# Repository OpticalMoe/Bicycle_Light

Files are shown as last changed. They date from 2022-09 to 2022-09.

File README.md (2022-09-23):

# Bicycle_Light
自行车灯系列

**开源协议：CC-BY-NC-SA 3.0，知识共享许可协议-署名-非商业使用-相同方式共享。**

---

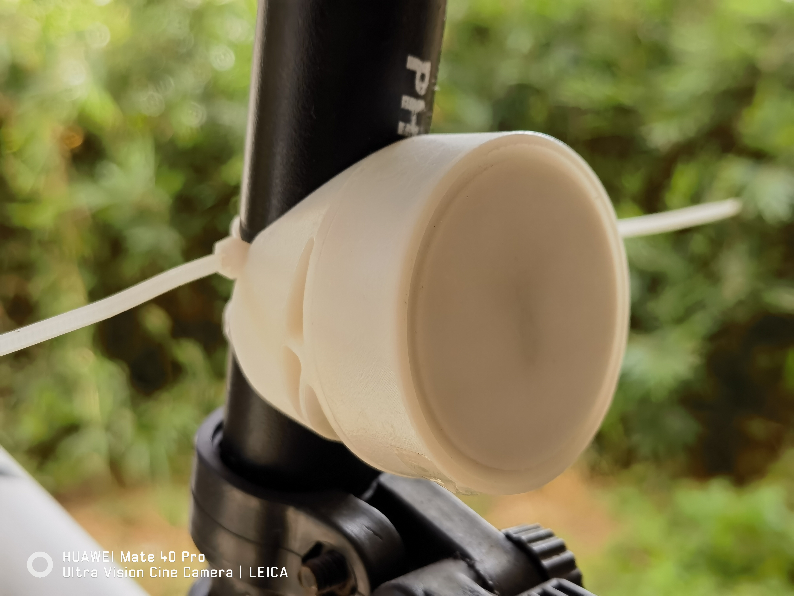
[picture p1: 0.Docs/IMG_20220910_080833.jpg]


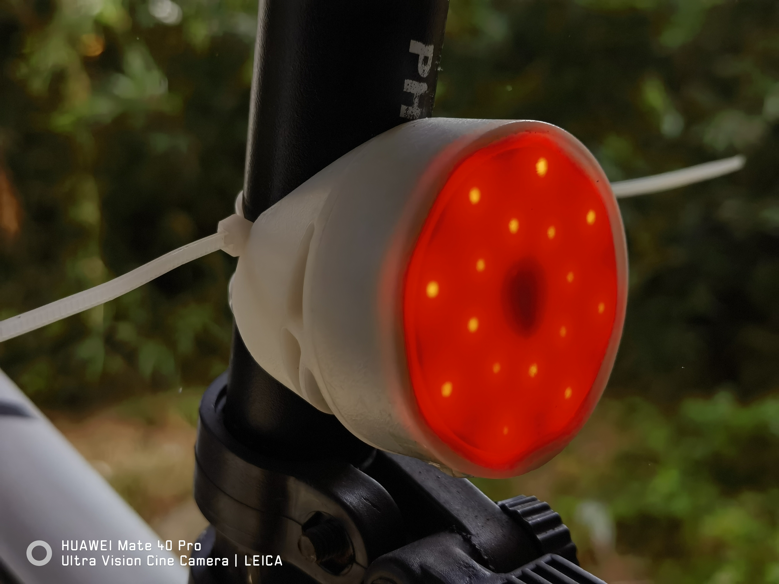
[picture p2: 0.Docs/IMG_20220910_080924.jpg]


> 目前仅有尾灯

# 尾灯

> 已知问题： (寒假改)
> 
>   1. 待机电流大，800mAh电池也就待机三天左右。下一版将会给非mcu器件加电子开关，待机时断开电源；
> 
>   2. 环境光API写了，逻辑部分没写；
> 
>   3. STC是QFN封装，对烙铁用户不友好；
>
>   4. 霍尔传感器“防盗”没测试；
> 
>   5. 刹车功能较难触发（急刹和撞墙才能识别到），且过沟沟坎坎会误触发。下一版取消（或更换传感器）。
> 
>   6. STC手册说是可以使用模拟USB下载程序，但是我电脑无法枚举设备，被迫转了串口下载。现支持不断电下载。 ：(

## 硬件
https://oshwhub.com/opticalmoe/bicycle_light

1. STC8G1K08-QFN20；

2. 16通道LED恒流驱动 TM5020A；

3. TC4056A 设定400mA充电电流；

4. 800mAh聚合物电池，30*34mm；

## 固件
1. 晃动/按键开机，无动作20s/按键关机；

2. 正面左按键开关机，右按键显示电量。一颗灯代表10%。

## 结构
Fusion360

---

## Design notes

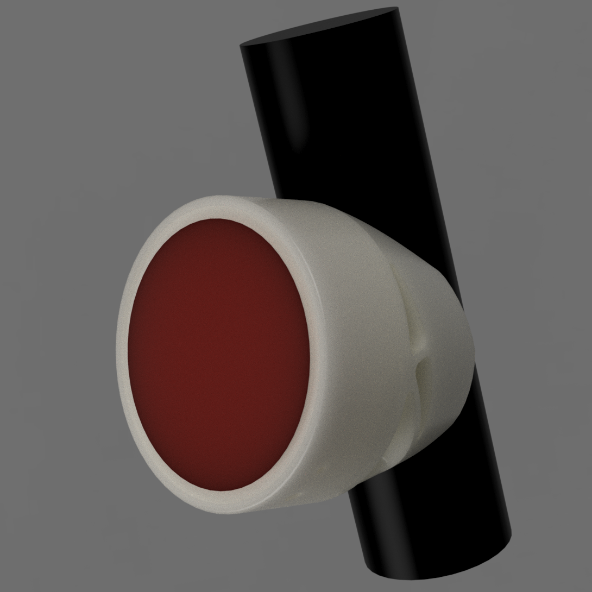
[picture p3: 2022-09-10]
5.结构/外壳 _F2.png

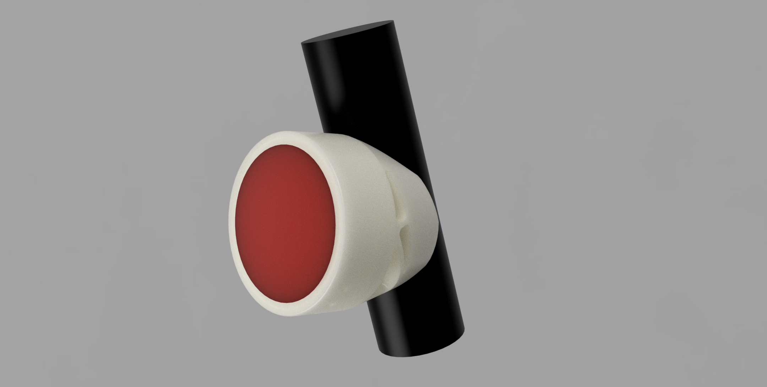
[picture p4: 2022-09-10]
5.结构/外壳 v16.png

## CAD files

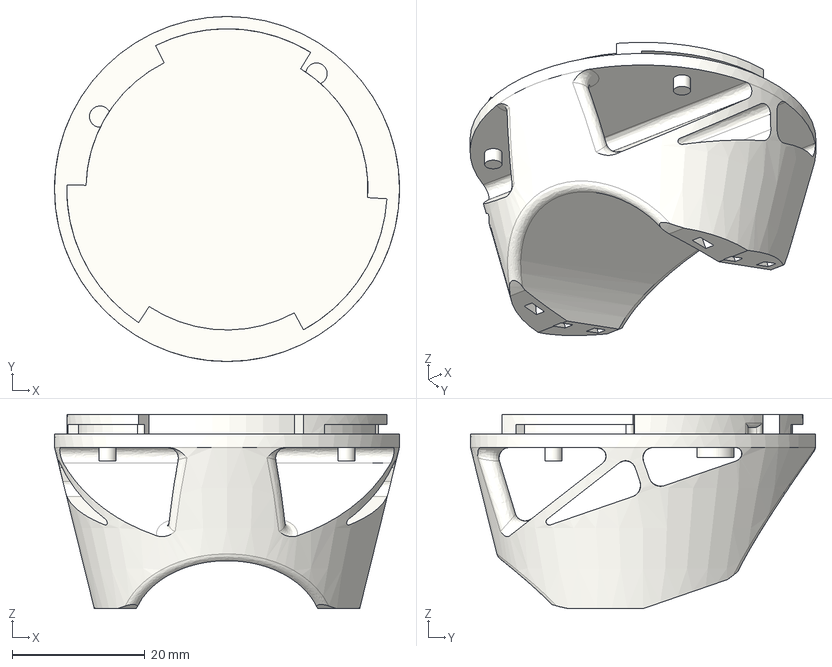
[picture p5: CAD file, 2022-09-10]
5.结构/底座_F2.step
52.0 x 52.0 x 29.3 mm

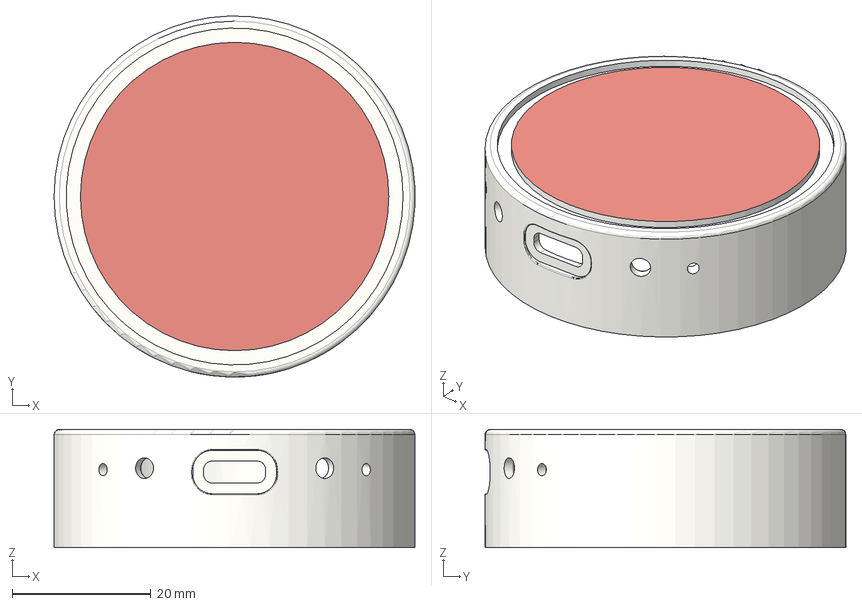
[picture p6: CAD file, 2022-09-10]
5.结构/灯壳_F2.step
52.0 x 52.0 x 17.0 mm

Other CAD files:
2.Firmware/V0.1/Objects/main.obj
2.Firmware/V0.1/Objects/peripheral.obj
2.Firmware/V0.1/Objects/light.obj
2.Firmware/V0.1/Objects/state.obj
2.Firmware/V0.1/Objects/STARTUP.obj
2.Firmware/V0.1/Objects/adc.obj

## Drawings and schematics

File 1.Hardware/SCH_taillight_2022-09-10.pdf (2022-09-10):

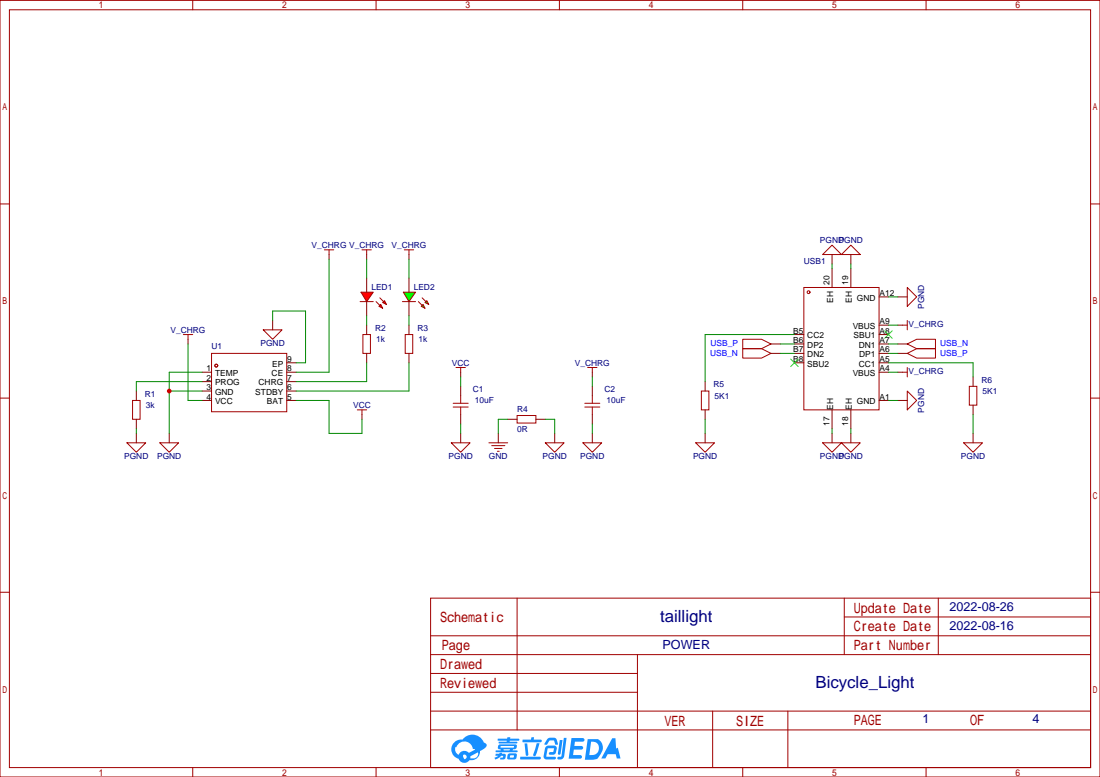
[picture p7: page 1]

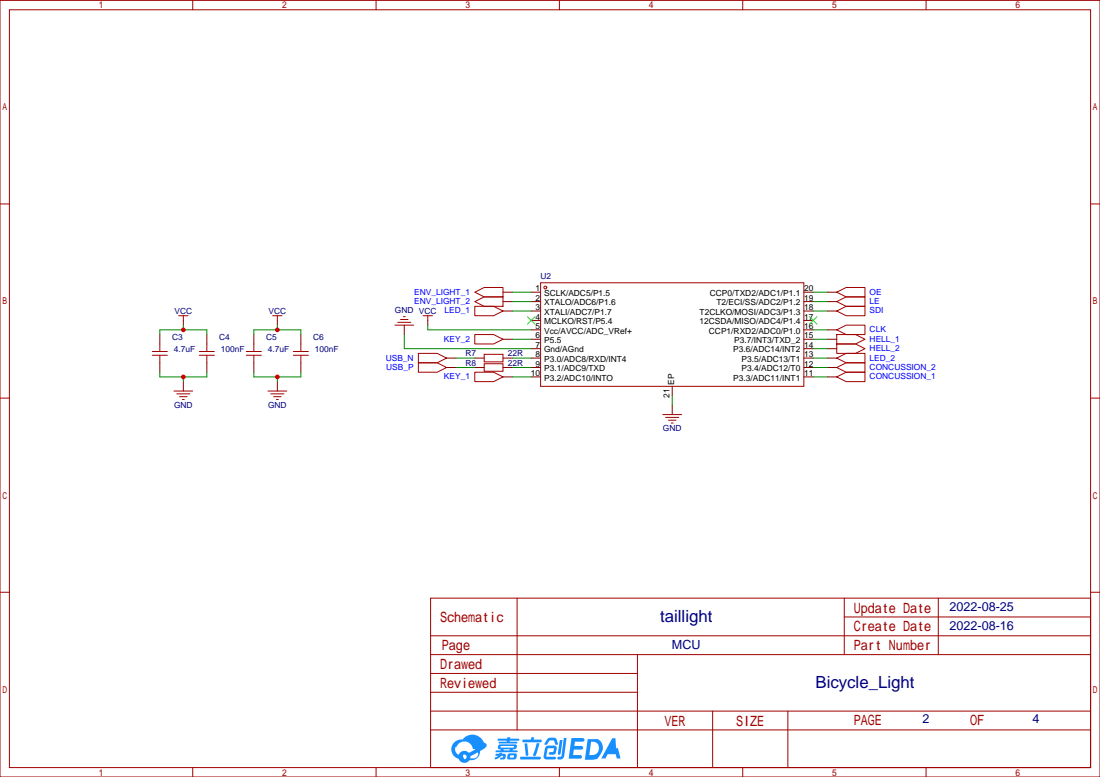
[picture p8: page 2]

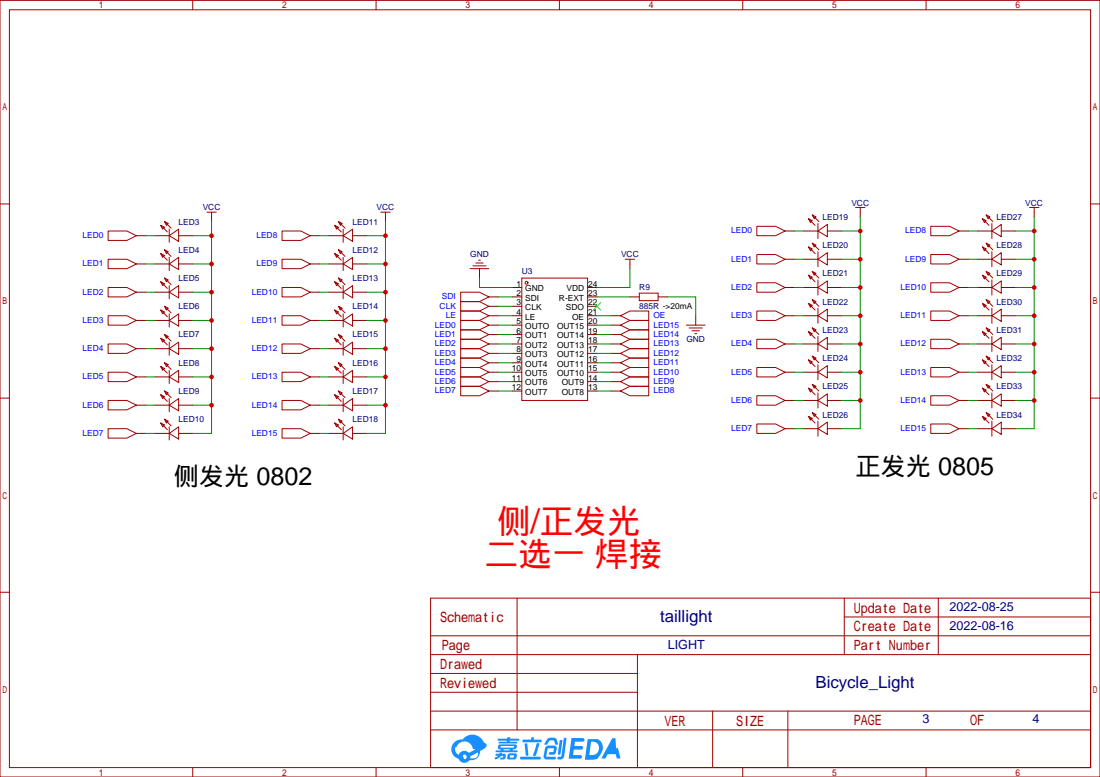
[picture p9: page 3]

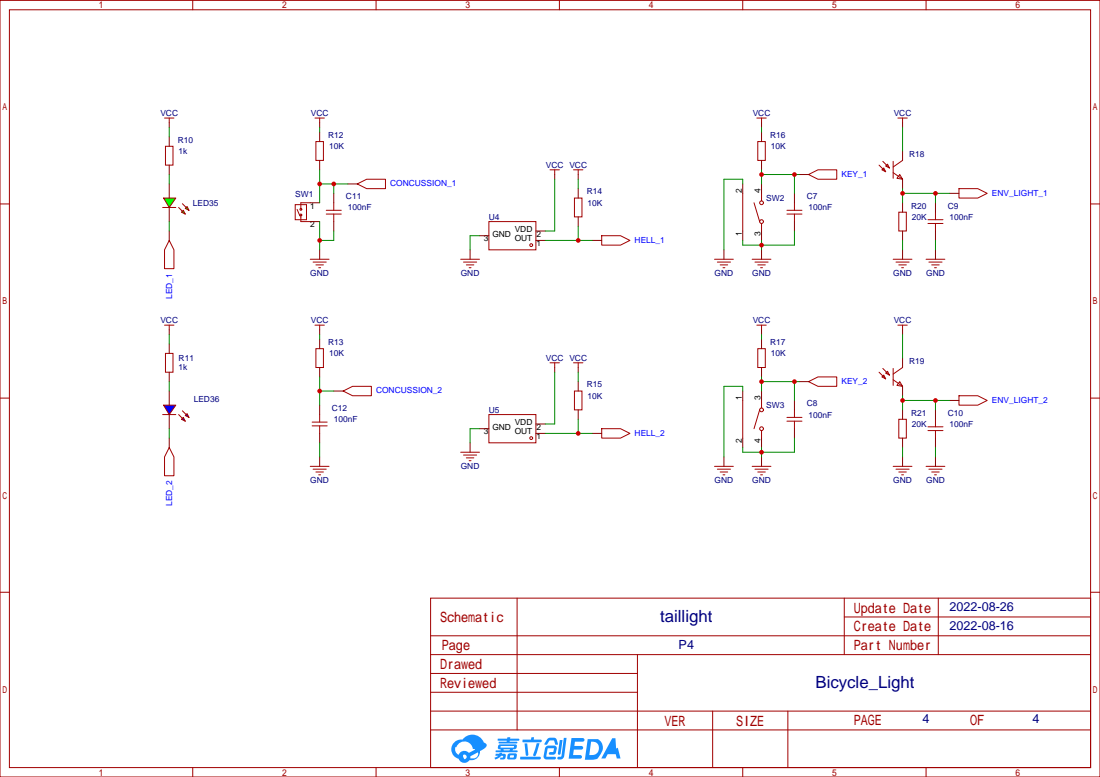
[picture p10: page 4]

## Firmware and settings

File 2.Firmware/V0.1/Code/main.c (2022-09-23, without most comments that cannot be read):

/*!
 * @file        main.c
 * @brief       
 * @copyright   Copyright (c) 2022 ChenYuanliang
 * @licence     CC-BY-NC-SA 3.0，知识共享许可协议-署名-非商业使用-相同方式共享。
 * @author      ChenYuanliang
 * @version     V1.0
 * @date        2022-09-01
 * @url         https://github.com/OpticalMoe
 */
 
#include "stc8gxx.h"
#include <stdio.h>
#include <intrins.h>
#include "light.h"
#include "adc.h"
#include "peripheral.h"
#include "state.h"

void Delay600us()		//@12.000MHz
{
	unsigned char i, j;

	i = 10;
	j = 87;
	do
	{
		while (--j);
	} while (--i);
}



void Delay1ms()		//@12.000MHz
{
	unsigned char i, j;

	i = 16;
	j = 147;
	do
	{
		while (--j);
	} while (--i);
}

void delay_ms(int number) 
{
    while(number--)
    {
       Delay1ms(); 
    }
}

void main()
{
    int i, j;
    unsigned short temp = 0;
    unsigned short battery_light = 0x0000;

    per_io_init();
    per_int_init();
    adc_init();
    light_init();
    timer_init();
    per_usart_init();
    reset_state();
    EA = 1; 
    
    while (1)
    {        
//        if (time_get_boot_time() % 500 == 0)
//        {
//            LED_B = !LED_B;
////            printf("power: 0x%02x\t", power);
//            
//            printf("cur: %d\tshut: %d\tbreak: %d \r\n", 
//                    (int)(time_get_boot_time() / 1000), (int)(time_get_shutdown() / 1000), 
//                        time_get_break());
//        }
                    
        if (power == WAKE)
        {
            printf("Start\r\n");
            power = RUN;
            light_running(TURN_ON);
        }
        else if (power == SLEEP)
        {
            printf("Sleep\r\n");
            light_running(TURN_OFF);
            per_power(SLEEP);
            continue;
        }
        else        //RUN
        {
            if (time_get_break() > 0)
            {
                printf("Break\r\n");
                if (time_get_break() % 500 < 250)
                    light(0xFFFF);
                else                    
                    light(0x0000);
            }
            else if(time_get_battery() > 0)
            {
                if(battery == BAT)
                {
                    battery = NO;
                    light(0x0000);
                    light_reset_last_number();
                    LED_G = 0;
                    
                    temp = adc_get_battery_electricity();
//                    temp = 10;
                    printf("Battery: %d %% \tV: %d\r\n", temp, adc_get_voltage(ADC_1_19));
                    temp = (unsigned short)(temp / 10.0 + 0.5);
                    battery_light = 0;
                    while(temp > 0)
                    {
                        battery_light <<= 1;
                        ++battery_light;
                        --temp;
                    }
                    temp = 0;
                }
                else if (time_get_battery() % 500 == 0)
                {
                    ++temp;
                    light(light_get_last_number() | (battery_light & (0x0001 << temp)));
                }
            }
            else                    //RUN
            {
                LED_G = 1;
                if (time_get_boot_time() % 3000 < 1000)
                    light(0x0000);
                else if (time_get_boot_time() % 3000 < 2000)
                    light(0x5555);
                else
                    light(0xAAAA);
            }
        }
        
        Delay600us();
    }
}

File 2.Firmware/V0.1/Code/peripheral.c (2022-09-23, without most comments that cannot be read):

/*!
 * @file        peripheral.c
 * @brief       
 * @copyright   Copyright (c) 2022 ChenYuanliang
 * @licence     CC-BY-NC-SA 3.0，知识共享许可协议-署名-非商业使用-相同方式共享。
 * @author      ChenYuanliang
 * @version     V1.0
 * @date        2022-09-01
 * @url         https://github.com/OpticalMoe
 */
 
#include "peripheral.h"
#include "stc8gxx.h"
#include <intrins.h>
#include <stdio.h>
#include "state.h"

/*


    INTCLKO |= 0x40;
    void Int4Isr() interrupt 16
    { 
        IAP_CONTR = 0x60;

    }

    SCON = 0x50;
    TMOD = 0x00; 
    AUXR = 0x40; 
    TH1 = BR115200 >> 8;
    TL1 = BR115200; 
    TR1 = 1; 
    ES = 1; 
    stage = 0;
    void UartIsr() interrupt 4 {...}
        

    IT0 = 0;

    EX0 = 1;
    IT1 = 0;

    EX1 = 1;
    INTCLKO = EX2;
    INTCLKO |= EX3;
    INTCLKO |= EX4;
    void INT0_Isr() interrupt 0 
    {
        P10 = !P10;
    }
    

    #define IDL             0x01                    //PCON.0
    #define PD              0x02                    //PCON.1
    PCON = IDL;

    _nop_();

*/

enum POWER power;

// usart
void Uart_SendChar(unsigned char  dat)
{
    SBUF = dat; 
    while(!TI); 
    TI = 0; 
}

char putchar(char c)
{
    Uart_SendChar(c);
    return c;
}

void UartIsr() interrupt 4
{ 
//    char dat; 
    if (TI) 
    { 
//        TI = 0; 
    } 
    if (RI) 
    {
        RI = 0; 
//        dat = SBUF; 
    } 
} 

// INT
void INT0_Isr() interrupt 0 
{
    if (power == WAKE)
        time_reset_shutdown();
    else
        power = SLEEP;
}

void INT1_Isr() interrupt 2 
{
    time_reset_shutdown();
}


void Int4Isr() interrupt 16
{ 
    IAP_CONTR = 0x60;

}


void per_usart_init(void)
{

    #define FOSC 12000000UL
    #define BD115200 (65536 - FOSC / 4 / 115200)
    SCON = 0x50;
    TMOD &= 0x0F;     
    AUXR &= 0x9E;
    AUXR |= 0x40;
    TH1 = BD115200 >> 8;
    TL1 = BD115200;
    TI = 1;
    TR1 = 1; 
    ES = 1;   
    printf("\r\n");
}

void per_io_init(void)
{
    /*

    P0M0 = 0x00;
    P0M1 = 0x00;
    P1M0 = 0xff;
    P1M1 = 0x00;
    P2M0 = 0x00;
    P2M1 = 0xff;
    P3M0 = 0xff;
    P3M1 = 0xff;
	*/	
    P1M0 = 0x00;	// OAAx OOOO  
    P1M1 = 0x60;
    P3M0 = 0x00;	// IIOI II??
    P3M1 = 0x00;
    P5M0 = 0x00;	//xxxX xxxx
    P5M1 = 0x00;    
}

void per_int_init(void)
{

    //#define KEY_LEFT    P32 //INT0  KEY_1
    IT0 = 1;
    EX0 = 1;
    IT1 = 1;
    EX1 = 1;
    

    INTCLKO |= 0x40;
}

void per_off_all(void)
{    
    light_off();
    LED_G = 1;
    LED_B = 1;
}

void reset_state(void)
{
    power = WAKE;
    time_reset_shutdown();
    time_break_zero();
}

void per_power(enum POWER _power)
{
    per_off_all();

    if (_power > SLEEP)
        return;
    PCON = _power;
    _nop_();

    reset_state();
}
